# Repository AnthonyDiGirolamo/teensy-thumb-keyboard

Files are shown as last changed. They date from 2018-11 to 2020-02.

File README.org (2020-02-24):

* teensy-thumb-keyboard

  Handheld tactile switch keyboard for Teensy 3.2 compatible boards.

  - [[https://www.tindie.com/products/15575/][Teensy Thumb Keyboard - PCB only]] - Tindie product page and ordering
  - [[https://hackaday.io/project/162281-teensy-thumb-keyboard][hackaday.io page]] - more photos, info and project logs
  - [[https://www.thingiverse.com/thing:3209958][thingiverse 'HyperPixel 4 & Raspberry Pi 3 B+ Handheld' page]]

*** v1.1 Photo
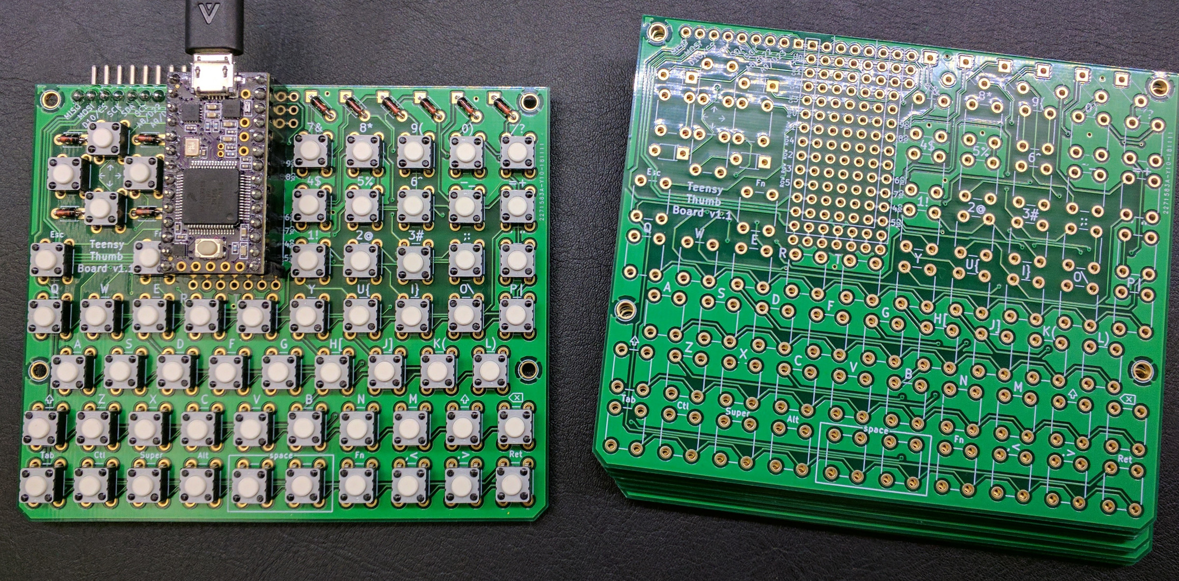
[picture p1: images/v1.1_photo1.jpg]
    

** Features
   - 60 keys arranged in a 6x10 matrix (uses 16 pins on the microcontroller).
   - Silkscreen has a qwerty layout with number keys arranged in a numpad.
   - Lead free ENIG-RoHs surface finish with 2oz copper.
   - SPI, I2C, and 2 additional GPIOs broken out.
   - Each pin along the edge of the Teensy is connected to one extra pin in the
     prototyping area.
   - Beginner friendly through hole soldering.
   - Example Arduino sketch [[https://github.com/AnthonyDiGirolamo/teensy-thumb-keyboard/tree/master/firmware][firmware]] provided. Additional details in the [[https://hackaday.io/project/162281-teensy-thumb-keyboard/log/156138-example-firmware-posted][Example
     Firmware Posted project log]].
   - Layout is completely customizable in the firmware.
   - [[https://github.com/qmk/qmk_firmware][qmk_firmware]] should also work however, I don't have an example running yet.

   *Three possible mounting options*

   1. Teensy on the front, mounted right-side up, with usb port facing north.
   2. Teensy on the back, mounted upside down, with usb port facing north or
      south.
   3. Teensy on the back, mounted upside down, with usb port facing south. Note:
      Breakout pins will only work as expected with USB facing north.

** Parts list for a fully working keyboard

   - 1x [[https://www.pjrc.com/store/teensy32.html][Teensy 3.2]] or [[https://www.pjrc.com/store/teensylc.html][Teensy LC]]. A [[https://www.tindie.com/products/TleraCorp/butterfly-stm32l433-development-board/][Butterfly STM32L433]] will also work (though not
     as a USB keyboard).
   - 10x 1N4148 Zener Diodes
   - 60x Panasonic EVQ-PAC04M Tacticle Switches. These are the quieter and higher
     quality switches. Some are available at [[https://www.digikey.com/products/en?keywords=EVQ-PAC04M][digikey]]. If you wish to use the 3d
     printed faceplate the overall switch height must be 4.3mm. These models will
     also work: EVQ-PAD04M EVQ-PAE04M EVQ-PAG04M. Otherwise any standard 6x6mm
     momentary switch will work.

** Ordering

   - [[https://www.tindie.com/products/15575/][Teensy Thumb Keyboard - PCB only]] Tindie product page
   - Ordering yourself from a PCB manufacturer:
     - https://oshpark.com instructions: upload the [[https://github.com/AnthonyDiGirolamo/teensy-thumb-keyboard/blob/master/hardware/v1.1/teensythumbboard.kicad_pcb][kicad pcb file]] file.
     - https://jlcpcb.com/quote instructions: upload the [[https://github.com/AnthonyDiGirolamo/teensy-thumb-keyboard/blob/master/hardware/v1.1/plots/gerbers.zip][gerber.zip file]] The
       settings I'd recommend are:
       - Layers: 2
       - Thickness: 1
       - Surface finish: LeadFree HASL-RoHs or ENIG-RoHs (don't want lead on a
         board you may be typing on)
       - Copper weight: 2oz (1oz is probably fine though, the heavier weight
         copper stands up better to repeated solder and desoldering I think)
       - Everything else default settings.

** Cases

   - Keyboard Faceplate [[https://a360.co/2QAJ0Qb][Fusion 360 Public Link]]
   - Raspberry Pi 3 B+ & HyperPixel4 Handheld [[https://a360.co/2QzHvla][Fusion 360 Public Link]]

** Firmware

   - The layout for USB keyboarding is defined in the ~usb_key_matrix~ variable
     in [[https://github.com/AnthonyDiGirolamo/teensy-thumb-keyboard/blob/master/firmware/LayoutThumbKeyboard.h#L109][LayoutThumbKeyboard.h]]

   - If you don't need a USB keyboard and are rolling your own hardware project
     then you can focus on the layout defined by the ~ascii_key_matrix~ variable
     in [[https://github.com/AnthonyDiGirolamo/teensy-thumb-keyboard/blob/master/firmware/LayoutThumbKeyboard.h#L74][LayoutThumbKeyboard.h]]

   - There are three layers defined: base, shift, and Fn layers.

   - USB can be disabled by commenting out define ~USE_TEENSY_USB_KEYBOARD~.

   - All the keyboardy goodness is handled by the ~keyboard_update();~ function
     called from inside the standard Arduino ~loop()~.

   - If you don't need the keys to behave like a keyboard you can gut most of
     that example and just use ~key_matrix.update();~ The KeyboardMatrix class
     handles reading the button states.

   - An alternative firmware option for a pure USB keyboard would be to run the
     excellent https://github.com/qmk/qmk_firmware.

*** Compiling on Windows machines

    1. Using a Teensy 3.2 or Teensy LC follow these directions for downloading
       and installing the teensyduino add-on to the Arduino environment:
       https://www.pjrc.com/teensy/td_download.html

    2. Once you have both installed. Launch the Arduino IDE and check what
       version of teensyduino is installed by going to *Help > About
       Arduino*. The about window for me shows *Arduino 1.8.9* in the upper left
       and *Teensyduino 1.46* in the upper right.

    3. Download the code archive from:
       https://github.com/AnthonyDiGirolamo/teensy-thumb-keyboard/archive/master.zip

    4. Extract that folder and move the firmware folder to:
       ~C:\Users\anthony\Documents\Arduino\firmware~ Substitute "anthony" with
       your username.

    5. Rename the ~firmware~ folder to ~teensy32_thumb_keyboard~

       The full path should be:
       ~C:\Users\anthony\Documents\Arduino\teensy32_thumb_keyboard~

       And these files should exist inside there:

       #+BEGIN_SRC text
         KeyboardMatrix.cpp
         KeyboardMatrix.h
         LayoutAppleM0110a.h
         LayoutCommon.h
         LayoutThumbKeyboard.h
         LinkedList.h
         teensy32_thumb_keyboard.ino
       #+END_SRC

    6. Open
       ~C:\Users\anthony\Documents\Arduino\teensy32_thumb_keyboard\teensy32_thumb_keyboard.ino~
       in the arduino IDE.

    7. In the *Tools* menu select *USB Type > Serial + Keyboard + Mouse + Joystick*

    8. Click the verify or upload buttons in the toolbar. If compilation is
       successful you should see a message like:

       #+BEGIN_SRC text
         Sketch uses 27920 bytes (10%) of program storage space. Maximum is 262144 bytes.
         Global variables use 6680 bytes (10%) of dynamic memory, leaving 58856 bytes for local variables. Maximum is 65536 bytes.
       #+END_SRC

*** Uploading the firmware without compiling

    If you don't wish to compile the firmware yourself you can use the
    precompiled hex files provided in the [[https://github.com/AnthonyDiGirolamo/teensy-thumb-keyboard/tree/master/firmware-compiled][firmware-compiled]] folder.

    To get them loaded on a Teensy 3.2 or LC download and install the
    [[https://www.pjrc.com/teensy/loader.html][Teensy Loader Application]] once installed plug in your teensy board and load
    the correct firmware file:

    - [[https://www.pjrc.com/store/teensy32.html][Teensy 3.2]]: ~teensy32_thumb_keyboard.ino-teensy32.hex~
    - [[https://www.pjrc.com/store/teensylc.html][Teensy LC]]: ~teensy32_thumb_keyboard.ino-teensyLC.hex~

** Alternate Versions

   - [[https://github.com/AnthonyDiGirolamo/i2c-thumb-keyboard][i2c-thumb-keyboard]]

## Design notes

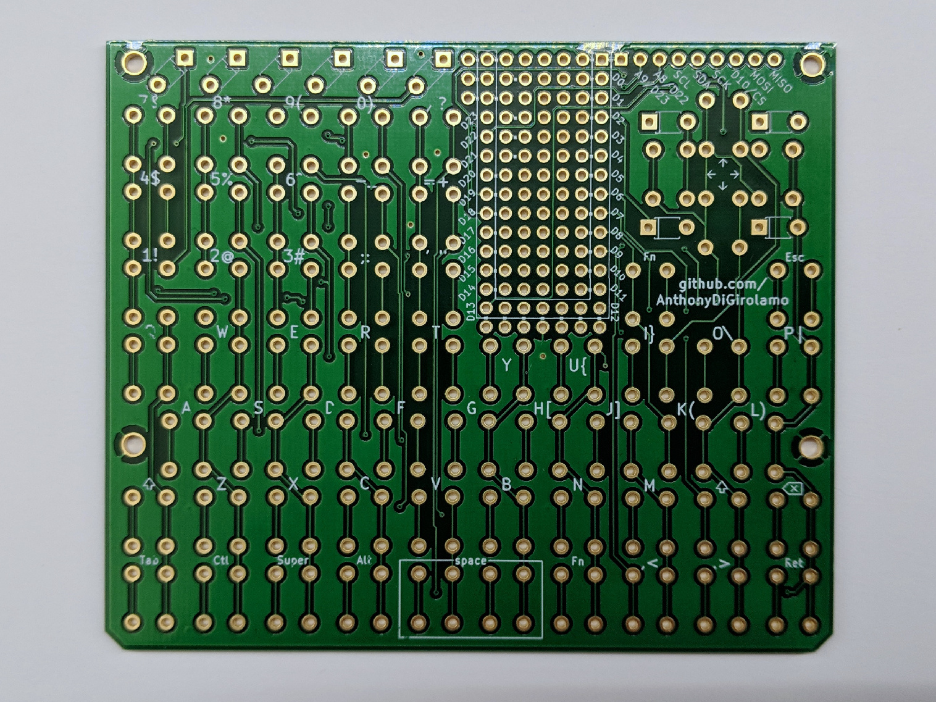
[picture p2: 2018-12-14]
images/ttb_photo_empty_back.jpg

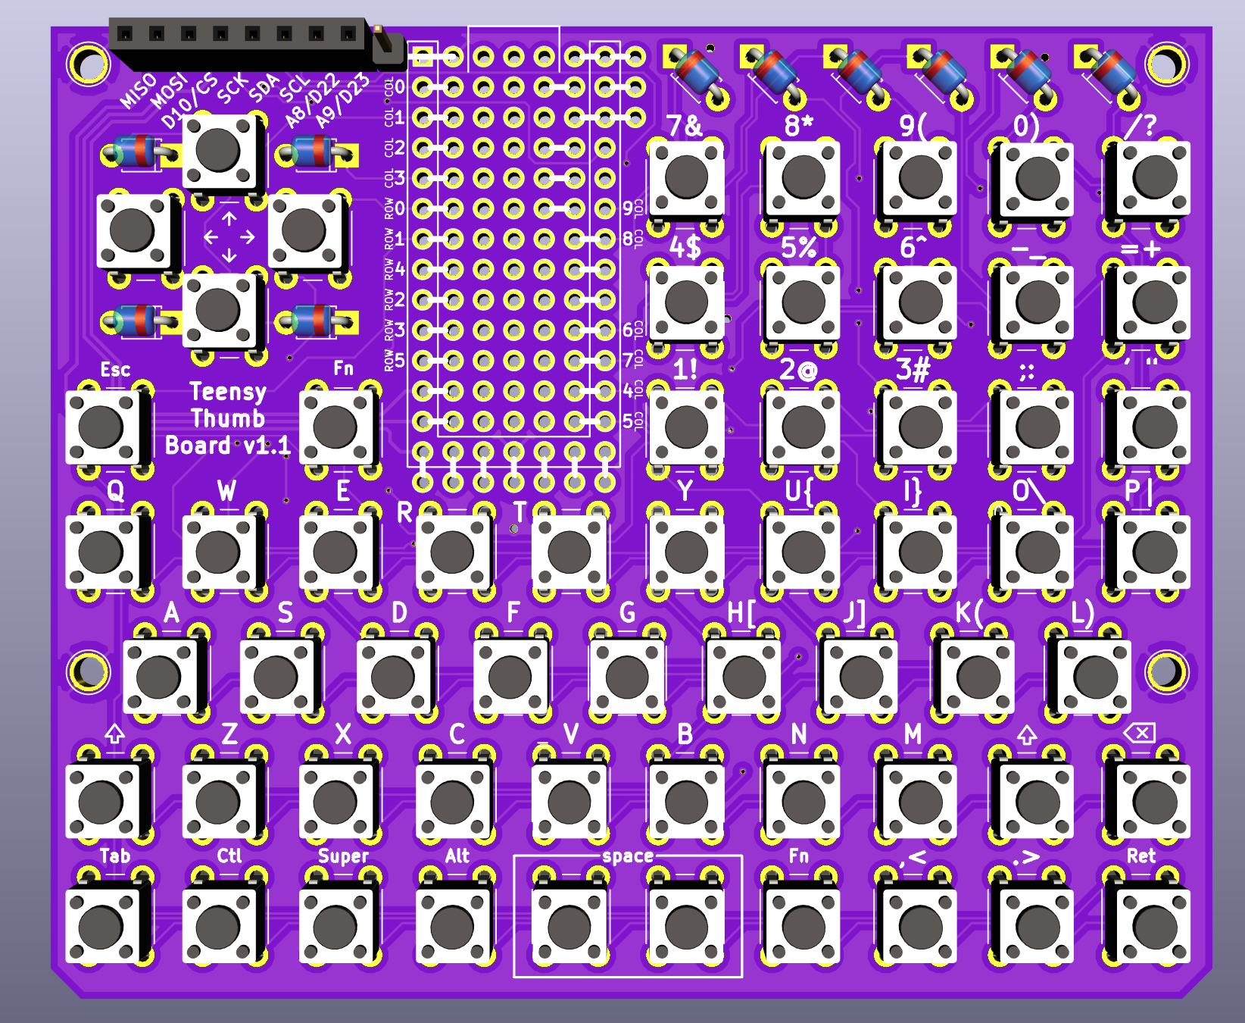
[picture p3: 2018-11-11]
images/v1.1_render.png

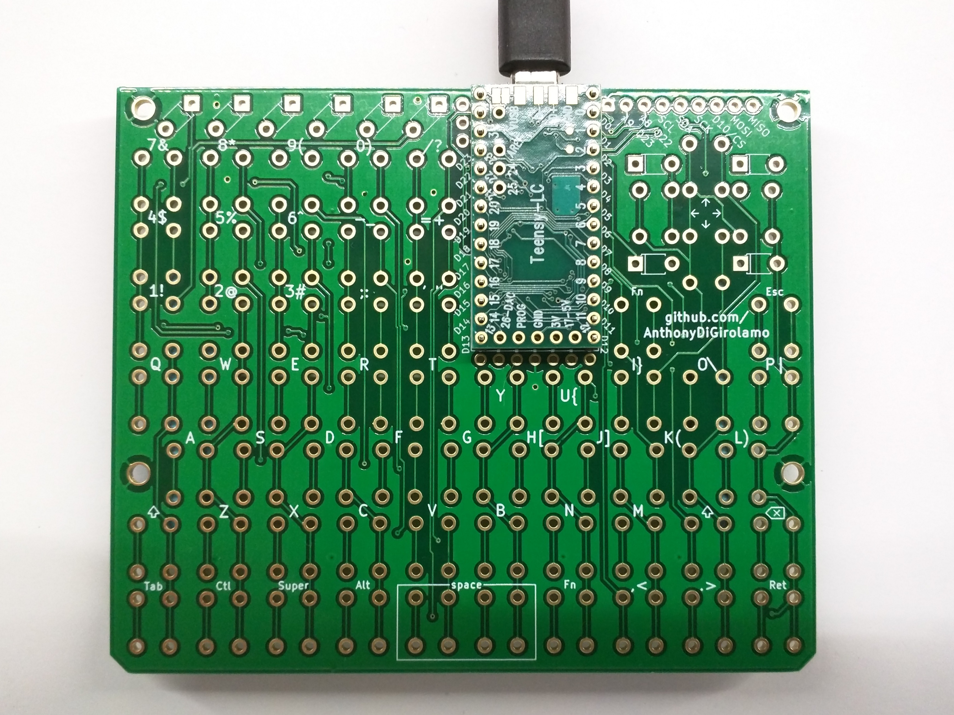
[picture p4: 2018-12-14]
images/ttb_photo_orientation2.jpg

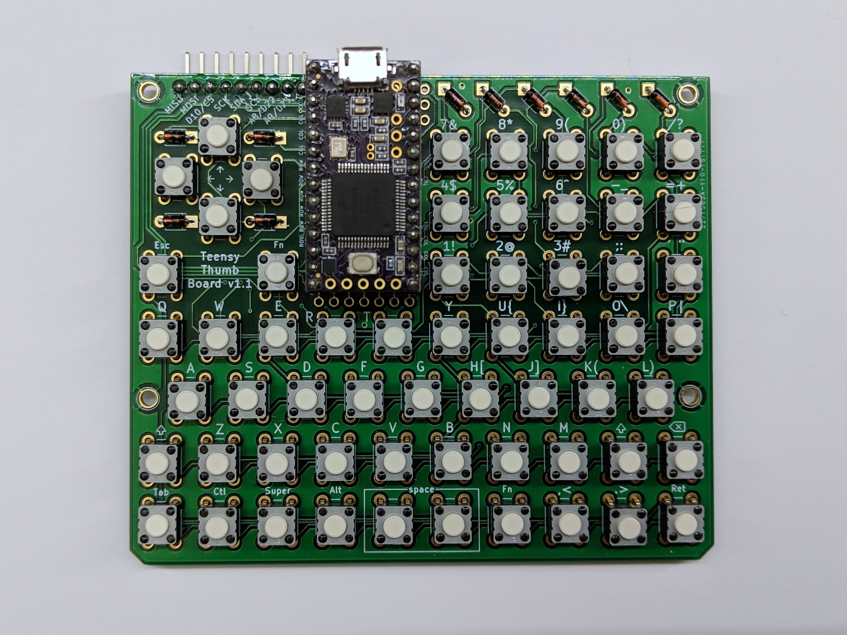
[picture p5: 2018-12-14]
images/ttb_photo_populated.jpg

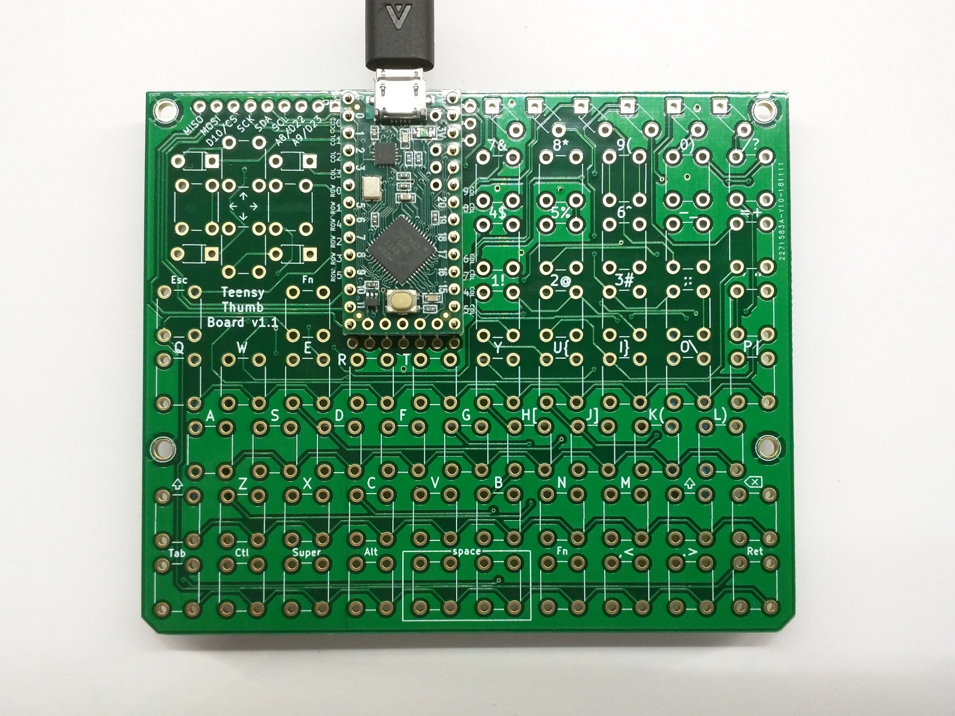
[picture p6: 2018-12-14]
images/ttb_photo_orientation1.jpg

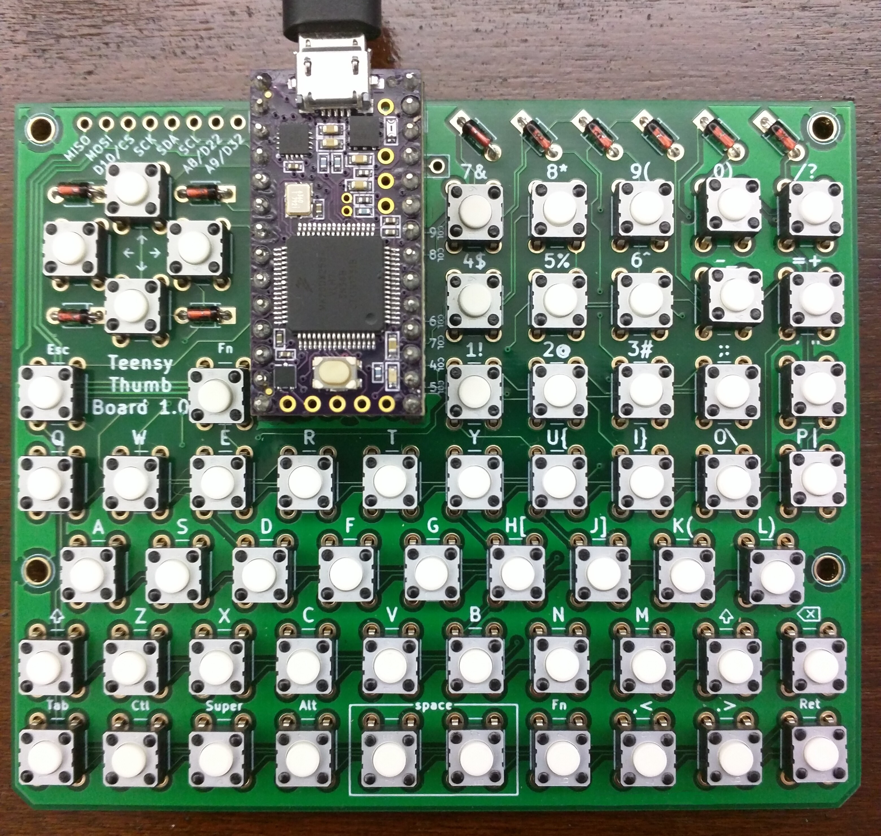
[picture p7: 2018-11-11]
images/v1.0_photo1.jpg

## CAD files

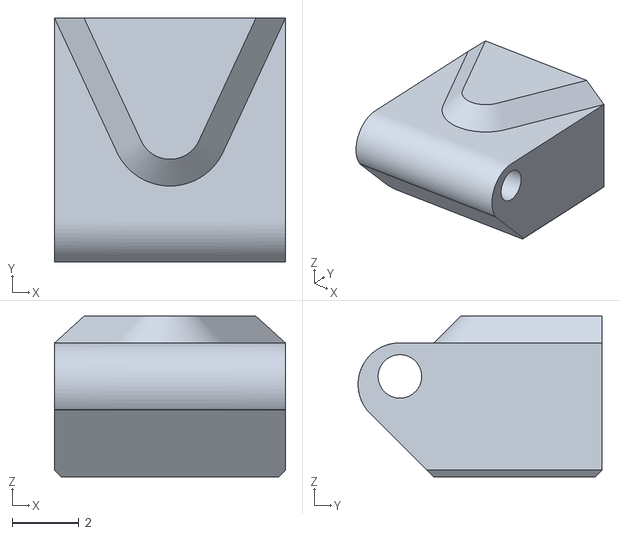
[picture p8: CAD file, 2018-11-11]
case/KeyFaceplate/Key.stl
6.90 x 7.28 x 4.80

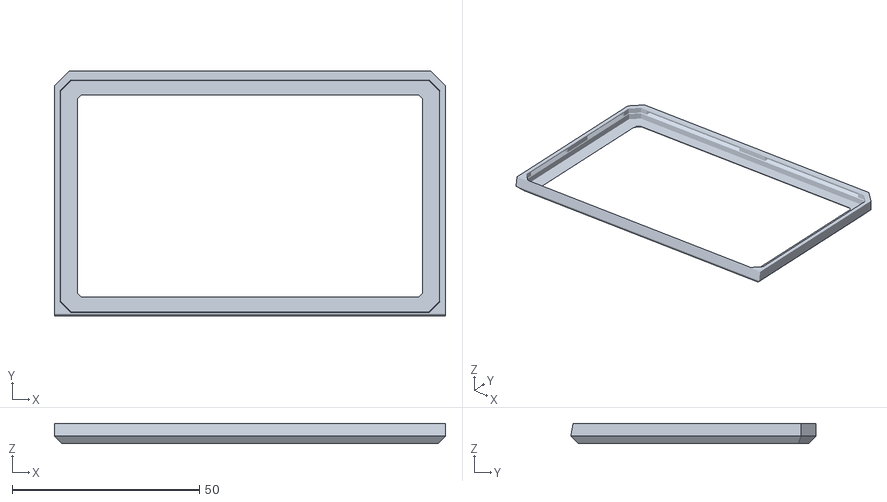
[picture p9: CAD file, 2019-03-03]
case/RaspberryPi3-HyperPixel4-Handheld/LCDBezel-TouchVersion.stl
104.4 x 65.5 x 5.40

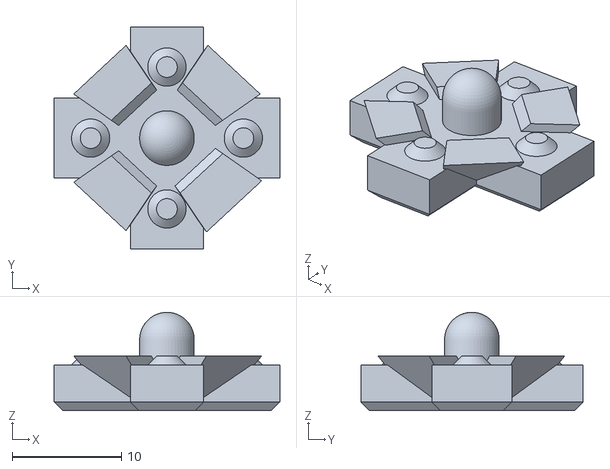
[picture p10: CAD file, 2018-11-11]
case/KeyFaceplate/DPad.stl
20.7 x 20.3 x 9.00

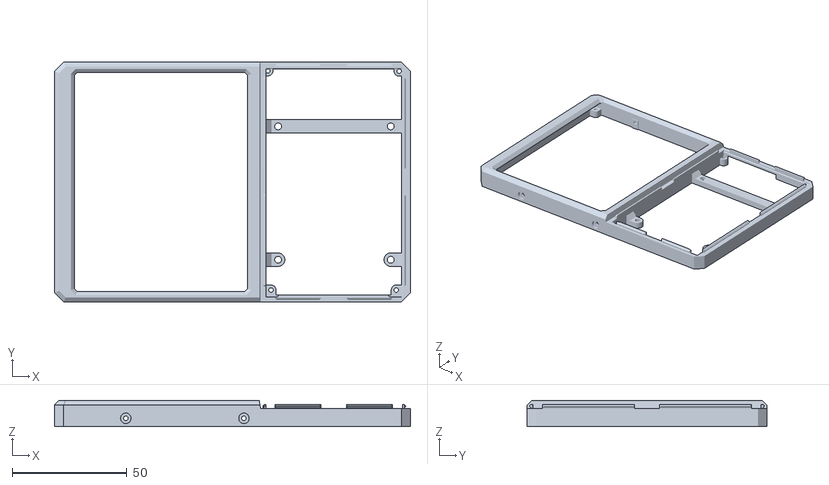
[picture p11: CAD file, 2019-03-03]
case/RaspberryPi3-HyperPixel4-Handheld/Support1_v2.stl
154.9 x 104.4 x 11.4

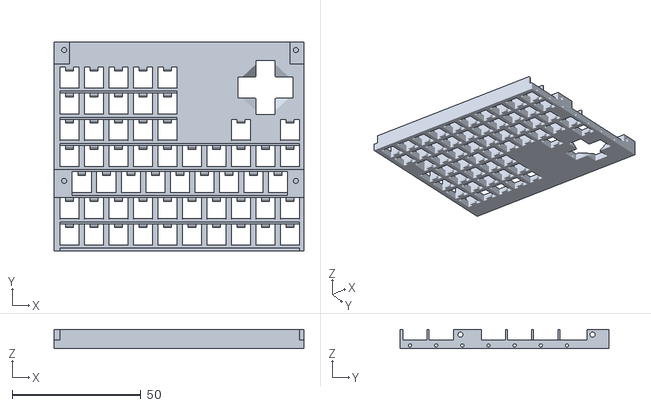
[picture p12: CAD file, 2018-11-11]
case/KeyFaceplate/KeyFaceplate.stl
97.2 x 81.3 x 7.40

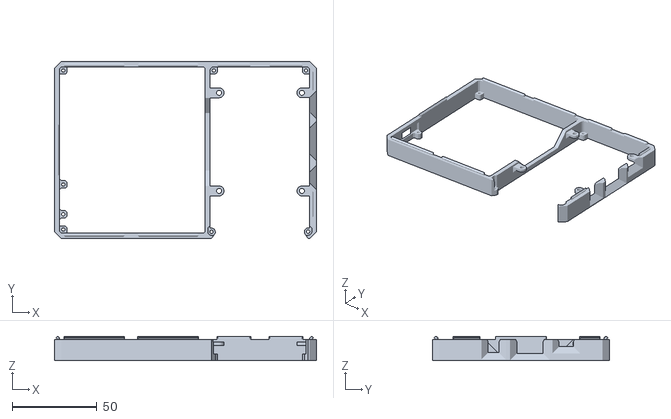
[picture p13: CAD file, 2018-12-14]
case/RaspberryPi3-HyperPixel4-Handheld/Support2.stl
154.9 x 104.4 x 14.4

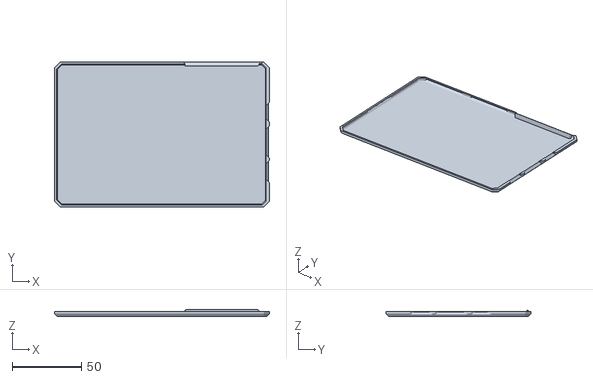
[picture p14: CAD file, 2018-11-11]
case/RaspberryPi3-HyperPixel4-Handheld/Back.stl
154.9 x 104.4 x 4.90

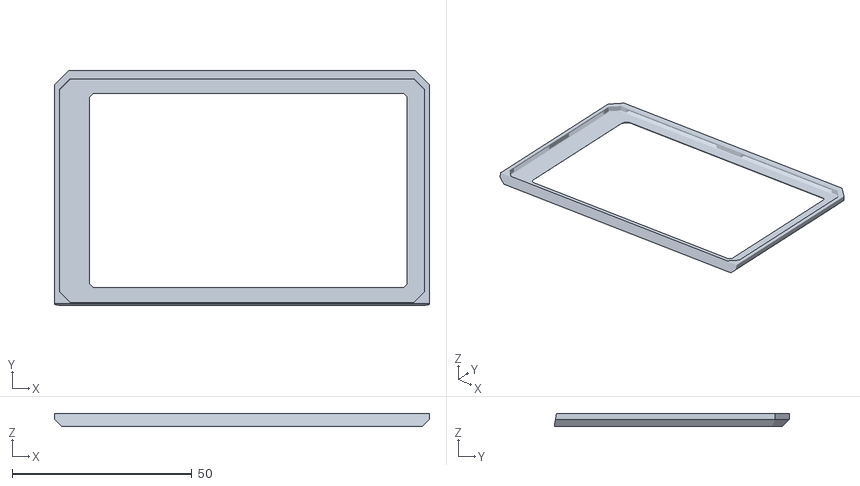
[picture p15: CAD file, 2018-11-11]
case/RaspberryPi3-HyperPixel4-Handheld/LCDBezel-NoTouch.stl
104.4 x 65.5 x 3.60

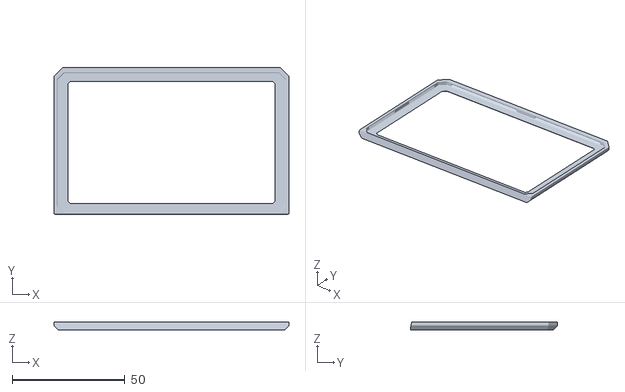
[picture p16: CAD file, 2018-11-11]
case/RaspberryPi3-HyperPixel4-Handheld/LCDBezel-NoTouch-Widened.stl
104.4 x 65.5 x 3.60

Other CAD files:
case/RaspberryPi3-HyperPixel4-Handheld/Support1.stl

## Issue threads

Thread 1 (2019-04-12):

Release example firmware compiled .hex files

0x0f0f0f, 2019-04-12:
on linux the arduino IDE & teensyduino are quite bulky and packages are not available on many distributions, plus, i've already soldered my teensy to the board.

could you please release a compiled example firmware .hex file for the standard USB US keyboard behavior?  `teensy_loader_cli` is easier to build and install rather than the whole arduino ide

AnthonyDiGirolamo, 2019-04-24:
Good idea! I'll get hex files for the teensy 3.2 and LC added soon.

AnthonyDiGirolamo, 2019-07-29:
Finally got around to uploading these. See: https://github.com/AnthonyDiGirolamo/teensy-thumb-keyboard#uploading-the-firmware-without-compiling

Closed 2019-07-29.

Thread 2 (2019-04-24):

Different language layout

teldra, 2019-04-24:
I build this keyboard successfully and it is working when setting Xorg to an english layout. But most of my computers are set to a different keyboard layout (german). So, when I press '/' on the keyboard I get '-'.

How do I change the send keycode, when using 'usb_key_matrix'? Changing 'Tools->Keyboard Layout' to German in Arduino IDE is not working.

AnthonyDiGirolamo, 2019-04-24:
I think it's because I'm using `Keyboard.press()` and `Keyboard.release()`. According to https://www.pjrc.com/teensy/td_keyboard.html the layout option in the arduino IDE only affects `Keyboard.print()` and `Keyboard.write()`. I didn't know that :sweat_smile:

To fix I think you'd have to update or copy [LayoutThumbKeyboard.h](https://github.com/AnthonyDiGirolamo/teensy-thumb-keyboard/blob/master/firmware/LayoutThumbKeyboard.h) to use different key codes in `usb_key_matrix`.

Here's what <kbd>/</kbd> would be with the German layout option:
```c
#define ASCII_2F	KEY_7 + SHIFT_MASK			// 47 /
```

So you'd have to change `KEY_SLASH` in [LayoutThumbKeyboard.h](https://github.com/AnthonyDiGirolamo/teensy-thumb-keyboard/blob/master/firmware/LayoutThumbKeyboard.h#L112) to `KEY_7 + SHIFT_MASK`.

Full list of conversions is in [https://github.com/PaulStoffregen/cores/blob/master/teensy3/keylayouts.h#L562](https://github.com/PaulStoffregen/cores/blob/master/teensy3/keylayouts.h#L562).
You would still need to select German in the Arduino IDE to make sure `SHIFT_MASK` and other defined values are correct.

If you make a new `LayoutGermanThumbKeyboard.h` and send me a pull request I can add it to the repo.

teldra, 2019-04-24:
When I change ```KEY_SLASH``` to  ```KEY_7 + SHIFT_MASK``` I get a ```<```.
And when I set ```KEY_EQUAL``` to ```KEY_0 + SHIFT_MASK``` I get a ```=``` when I press it with or without shift.

teldra, 2019-04-25:
I think I found a solution:
https://github.com/teldra/teensy-thumb-keyboard/blob/master/firmware/KeyboardMatrix.h
https://github.com/teldra/teensy-thumb-keyboard/blob/master/firmware/teensy32_thumb_keyboard.ino
but I wonder, if it is an elegant or correct one. ;) (First time working with Arduino)

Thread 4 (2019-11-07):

Oneshot Shift/Control/Alt/Super not working

Kulllerkeks, 2019-11-07:
After putting all the parts together i recognise that most of the oneShot function isn't working.
oneshot Fn is working fine, Shift seems to have a problem. With the debug messages i can see that the Keys are transmitted in upper case but only lower keys appear in a text box (Tested on Win10 with German keyboard layout in the system settings, Us Layout in Arduino/Teensy settings). I tried using it on a Raspberry pi (Raspbian Buster) with the Layout in Raspbian set to US but encountered the same issue. I also used the Recompiled hex and got the same behavior.

Maybe there was a change in the Teensy libs. It seems that, for normal characters shift needs to be held to get a upper case Character recognized. If i hold shift while pressing another key it is recognized as a upper case character.

Could you try to confirm it? or am i doing something wrong?

And as far as i can see in the firmware, the code for oneshot Control/Alt and Super is missing.

I will try changing the firmware at the weekend but it would be great to know if i am not the only one with this issue.

Otherwise, great work, it helped me tremendously!

Edit: Forgot to mention that i am using a Teensy LC

Closed 2020-10-21.

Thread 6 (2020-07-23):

keyboard not working

graysonmagg, 2020-07-23:
I have ordered the board from JLCpcb, as well as all of the components listed. After soldering everything together, and installing the software, it doesn't work. However, I am testing it just by using it plugged into my MacBook. Is there any troubleshooting tips you'd suggest? I am pretty new to soldering, so I can't tell if it was the soldering, or if it was just me installing the software wrong, so I have attached some pictures as well.

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

RogueColonel, 2020-09-10:
I could be mistaken but I think you've got the Teensy aligned wrongly,

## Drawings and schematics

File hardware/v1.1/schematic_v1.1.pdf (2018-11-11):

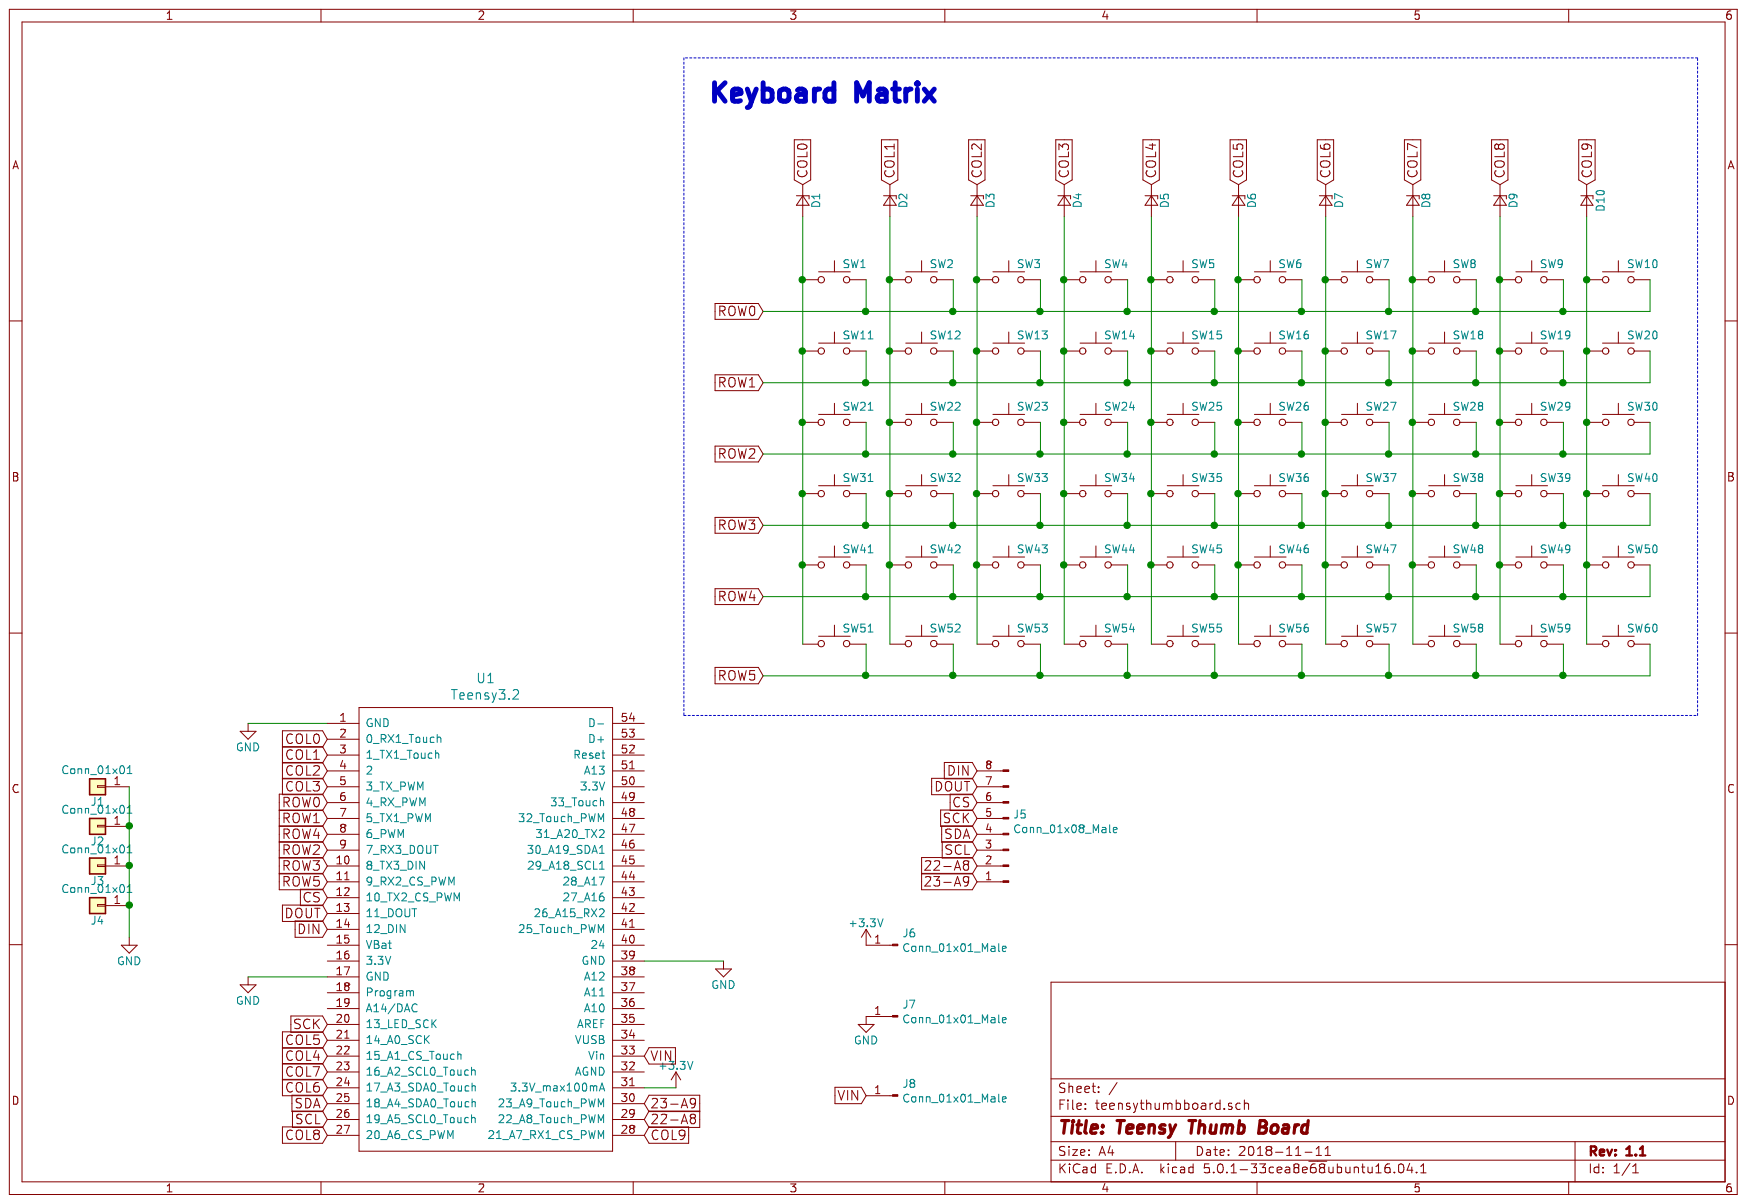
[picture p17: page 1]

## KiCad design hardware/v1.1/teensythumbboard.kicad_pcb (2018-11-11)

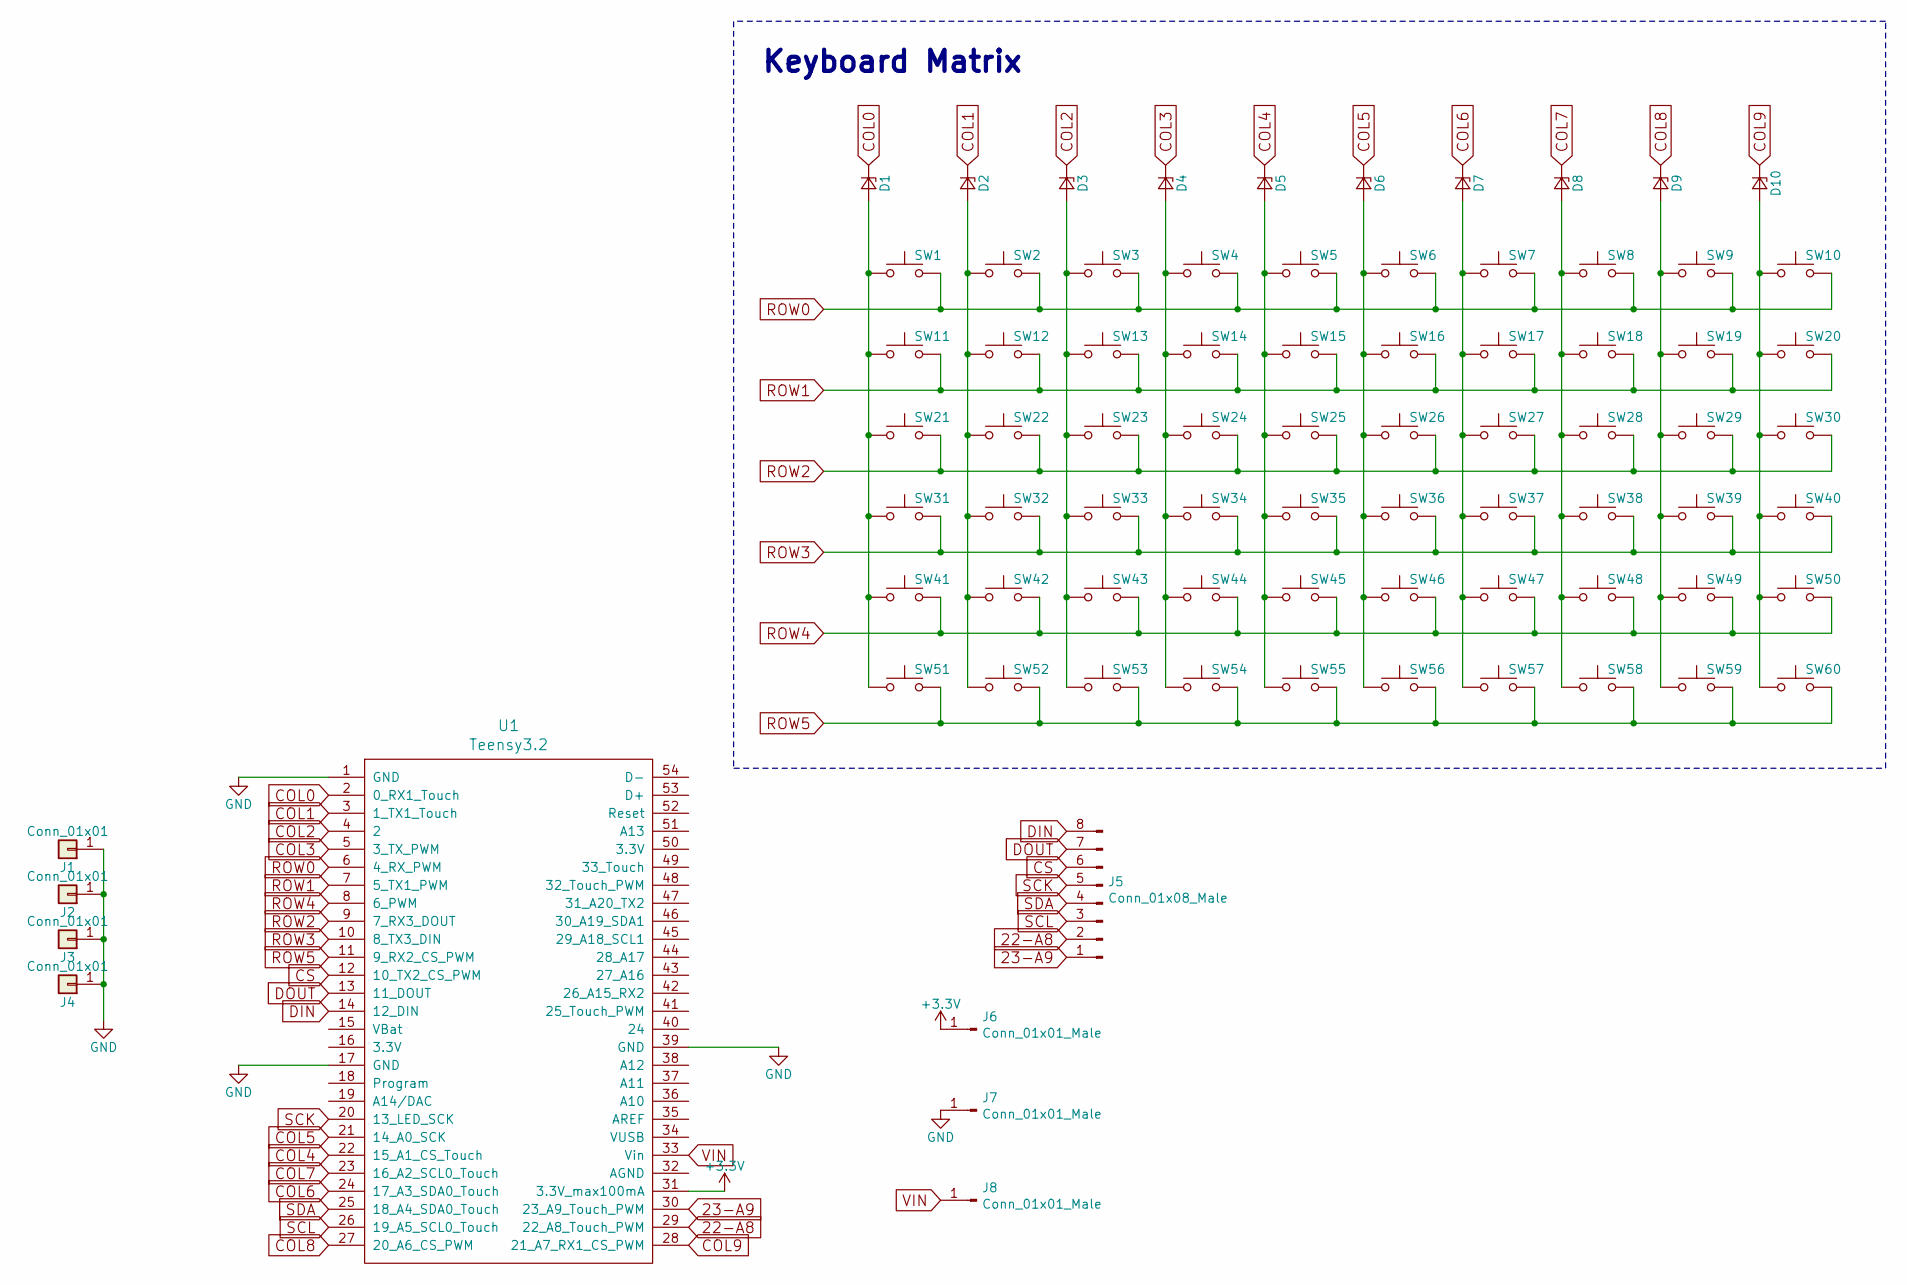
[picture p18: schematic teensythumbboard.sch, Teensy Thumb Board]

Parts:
D1, D2, D3, D4, D5, D6, D7, D8, D9, D10: D_Zener_Small; D_T-1_P5.08mm_Horizontal
J1, J2, J3, J4: Conn_01x01; 2.5MountingHole
J5: Conn_01x08_Male; PinSocket_1x08_P2.54mm_Vertical
J6, J7, J8: Conn_01x01_Male; PinHeader_1x01_P2.54mm_Vertical
SW1, SW2, SW3, SW4, SW5, SW6, SW7, SW8, SW9, SW10, SW11, SW12, SW13, SW14, SW15, SW16, SW17, SW18, SW19, SW20, SW21, SW22, SW23, SW24, SW25, SW26, SW27, SW28, SW29, SW30, SW31, SW32, SW33, SW34, SW35, SW36, SW37, SW38, SW39, SW40, SW41, SW42, SW43, SW44, SW45, SW46, SW47, SW48, SW49, SW50, SW51, SW52, SW53, SW54, SW55, SW56, SW57, SW58, SW59, SW60: SW_Push; SW_PUSH_6mm
U1: Teensy3.2; Teensy32_InnerProto

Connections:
22-A8: J5.2, U1.29 (22_A8_Touch_PWM)
23-A9: J5.1, U1.30 (23_A9_Touch_PWM)
+3V3: J6.1, U1.31 (3.3V_max100mA)
COL0: D1.1 (K), U1.2 (0_RX1_Touch)
COL1: D2.1 (K), U1.3 (1_TX1_Touch)
COL2: D3.1 (K), U1.4 (2)
COL3: D4.1 (K), U1.5 (3_TX_PWM)
COL4: D5.1 (K), U1.22 (15_A1_CS_Touch)
COL5: D6.1 (K), U1.21 (14_A0_SCK)
COL6: D7.1 (K), U1.24 (17_A3_SDA0_Touch)
COL7: D8.1 (K), U1.23 (16_A2_SCL0_Touch)
COL8: D9.1 (K), U1.27 (20_A6_CS_PWM)
COL9: D10.1 (K), U1.28 (21_A7_RX1_CS_PWM)
CS: J5.6, U1.12 (10_TX2_CS_PWM)
DIN: J5.8, U1.14 (12_DIN)
DOUT: J5.7, U1.13 (11_DOUT)
GND: J1.1, J2.1, J3.1, J4.1, J7.1, U1.1 (GND), U1.17 (GND), U1.39 (GND)
unnamed: D1.2 (A), SW1.1, SW11.1, SW21.1, SW31.1, SW41.1, SW51.1
unnamed: D2.2 (A), SW2.1, SW12.1, SW22.1, SW32.1, SW42.1, SW52.1
unnamed: D3.2 (A), SW3.1, SW13.1, SW23.1, SW33.1, SW43.1, SW53.1
unnamed: D4.2 (A), SW4.1, SW14.1, SW24.1, SW34.1, SW44.1, SW54.1
unnamed: D5.2 (A), SW5.1, SW15.1, SW25.1, SW35.1, SW45.1, SW55.1
unnamed: D6.2 (A), SW6.1, SW16.1, SW26.1, SW36.1, SW46.1, SW56.1
unnamed: D7.2 (A), SW7.1, SW17.1, SW27.1, SW37.1, SW47.1, SW57.1
unnamed: D8.2 (A), SW8.1, SW18.1, SW28.1, SW38.1, SW48.1, SW58.1
unnamed: D9.2 (A), SW9.1, SW19.1, SW29.1, SW39.1, SW49.1, SW59.1
unnamed: D10.2 (A), SW10.1, SW20.1, SW30.1, SW40.1, SW50.1, SW60.1
ROW0: SW1.2, SW2.2, SW3.2, SW4.2, SW5.2, SW6.2, SW7.2, SW8.2, SW9.2, SW10.2, U1.6 (4_RX_PWM)
ROW1: SW11.2, SW12.2, SW13.2, SW14.2, SW15.2, SW16.2, SW17.2, SW18.2, SW19.2, SW20.2, U1.7 (5_TX1_PWM)
ROW2: SW21.2, SW22.2, SW23.2, SW24.2, SW25.2, SW26.2, SW27.2, SW28.2, SW29.2, SW30.2, U1.9 (7_RX3_DOUT)
ROW3: SW31.2, SW32.2, SW33.2, SW34.2, SW35.2, SW36.2, SW37.2, SW38.2, SW39.2, SW40.2, U1.10 (8_TX3_DIN)
ROW4: SW41.2, SW42.2, SW43.2, SW44.2, SW45.2, SW46.2, SW47.2, SW48.2, SW49.2, SW50.2, U1.8 (6_PWM)
ROW5: SW51.2, SW52.2, SW53.2, SW54.2, SW55.2, SW56.2, SW57.2, SW58.2, SW59.2, SW60.2, U1.11 (9_RX2_CS_PWM)
SCK: J5.5, U1.20 (13_LED_SCK)
SCL: J5.3, U1.26 (19_A5_SCL0_Touch)
SDA: J5.4, U1.25 (18_A4_SDA0_Touch)
VIN: J8.1, U1.33 (Vin)

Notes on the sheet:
Keyboard Matrix

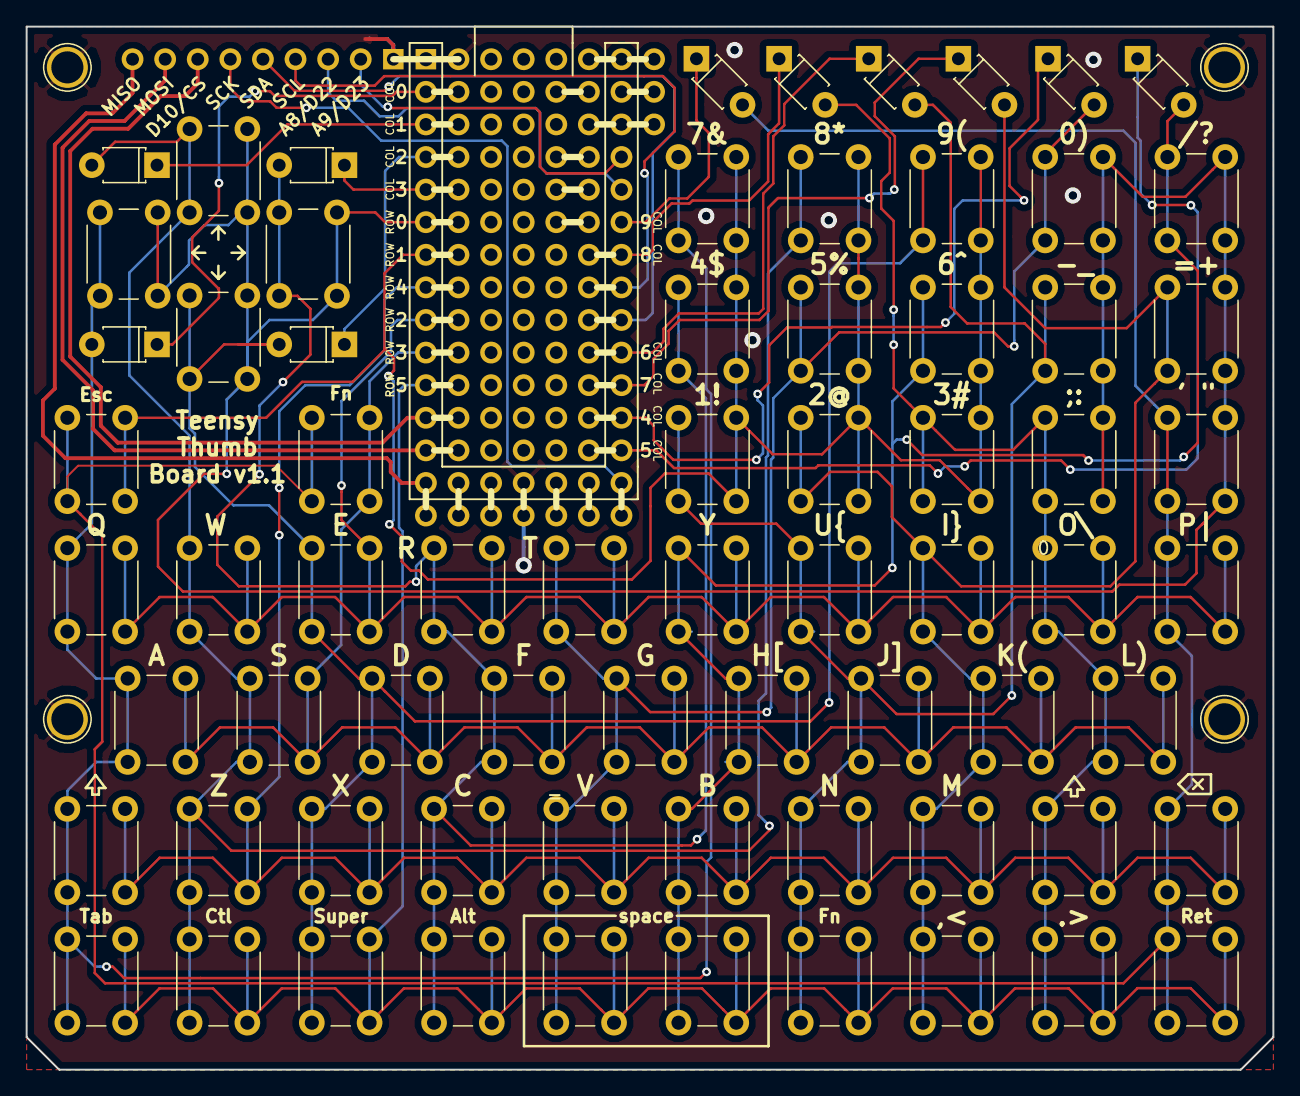
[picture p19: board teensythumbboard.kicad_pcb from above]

Board: 2 copper layers, 97.2 x 81.3 mm, 77 parts (0 on the bottom side), 35 nets.

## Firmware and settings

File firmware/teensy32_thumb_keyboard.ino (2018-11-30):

#include "KeyboardMatrix.h"

// Uncomment to show matrix debug messages over serial
// #define DEBUG


// --- LAYOUT OPTIONS ----------------------------------------------------------

// For TeensyThumbKeyboard:
#include "LayoutThumbKeyboard.h"
KeyboardMatrix key_matrix = KeyboardMatrix(NUM_ROWS, NUM_COLS,
                                           (uint8_t*) row_pins,
                                           (uint8_t*) col_pins,
                                           DIODE_DIRECTION_ROW_PIN_TO_COL_PIN);

// For AppleM0110a:
// #include "LayoutAppleM0110a.h"
// KeyboardMatrix key_matrix = KeyboardMatrix(NUM_ROWS, NUM_COLS,
//                                            (uint8_t*) row_pins,
//                                            (uint8_t*) col_pins,
//                                            DIODE_DIRECTION_COL_PIN_TO_ROW_PIN);

// --- ADDITIONAL FEATURES ----------------------------------------------------------

// Optional USB support using the Teensy Keyboard and Mouse classes
#define USE_TEENSY_USB_KEYBOARD

// Allow a single shift or fn key-press to apply the modifier to the next key press
#define ENABLE_ONESHOT_SHIFT_FN

// Auto-repeat Keypresses in firmware
#define ENABLE_AUTOREPEAT

// Initial delay before repeating a keypress
//   Units are in Microseconds: 1 millisecond = 1000 microseconds
#define HOLD_INTERVAL 300000

// Repeat interval after initial delay
#define REPEAT_INTERVAL 200000

// --- Code --------------------------------------------------------------------

// Represents the current keyboard state between updates
class KeyboardState {
public:
#ifdef ENABLE_ONESHOT_SHIFT_FN
  bool oneshot_shift = false;
  bool oneshot_fn = false;
  bool oneshot_ctrl = false;
  bool oneshot_super = false;
  bool oneshot_alt = false;
#endif

  uint8_t current_layer = 0;
  bool fn_lock = false;
  bool modifier_shift_held = false;
  bool modifier_fn_held = false;
  bool modifier_ctrl_held = false;
  bool modifier_alt_held = false;
  bool modifier_super_held = false;

#ifdef USE_TEENSY_USB_KEYBOARD
  // Mouse keystate variables
  uint8_t mouse_btn1_held = 0;
  uint8_t mouse_btn2_held = 0;
  uint8_t mouse_btn3_held = 0;
  uint8_t mousekey_repeat =  0;
  uint8_t mousekey_accel = 0;
  uint32_t mousekey_last_timer = 0;
#endif

};

KeyboardState keyboard_state = KeyboardState();


// --- Mouse key constants and functions ---------------------------------------
#ifdef USE_TEENSY_USB_KEYBOARD

// User configurable mouse speed values
#define MOUSEKEY_DELAY 100
#define MOUSEKEY_INTERVAL 10
#define MOUSEKEY_MAX_SPEED 7
#define MOUSEKEY_TIME_TO_MAX 255
#define MOUSEKEY_WHEEL_MAX_SPEED 7
#define MOUSEKEY_WHEEL_TIME_TO_MAX 255

#define MOUSEKEY_MOVE_MAX       127
#define MOUSEKEY_WHEEL_MAX      127
#define MOUSEKEY_MOVE_DELTA     5
#define MOUSEKEY_WHEEL_DELTA    1

// Mouse Key implementation from the tmk_keyboard firmware:
// https://github.com/tmk/tmk_keyboard/blob/master/tmk_core/common/mousekey.c

/*
 * Mouse keys acceleration algorithm
 *  http://en.wikipedia.org/wiki/Mouse_keys
 *
 *  speed = delta * max_speed * (repeat / time_to_max)**((1000+curve)/1000)
 */
/* milliseconds between the initial key press and first repeated motion event (0-2550) */
const uint8_t mk_delay = MOUSEKEY_DELAY/10;
/* milliseconds between repeated motion events (0-255) */
const uint8_t mk_interval = MOUSEKEY_INTERVAL;
/* steady speed (in action_delta units) applied each event (0-255) */
const uint8_t mk_max_speed = MOUSEKEY_MAX_SPEED;
/* number of events (count) accelerating to steady speed (0-255) */
const uint8_t mk_time_to_max = MOUSEKEY_TIME_TO_MAX;
/* ramp used to reach maximum pointer speed (NOT SUPPORTED) */
//int8_t mk_curve = 0;
/* wheel params */
const uint8_t mk_wheel_max_speed = MOUSEKEY_WHEEL_MAX_SPEED;
const uint8_t mk_wheel_time_to_max = MOUSEKEY_WHEEL_TIME_TO_MAX;

uint8_t mouse_move_unit(void) {
  uint16_t unit;
  if (keyboard_state.mousekey_accel & (1<<0)) {
    unit = (MOUSEKEY_MOVE_DELTA * mk_max_speed)/4;
  } else if (keyboard_state.mousekey_accel & (1<<1)) {
    unit = (MOUSEKEY_MOVE_DELTA * mk_max_speed)/2;
  } else if (keyboard_state.mousekey_accel & (1<<2)) {
    unit = (MOUSEKEY_MOVE_DELTA * mk_max_speed);
  } else if (keyboard_state.mousekey_repeat == 0) {
    unit = MOUSEKEY_MOVE_DELTA;
  } else if (keyboard_state.mousekey_repeat >= mk_time_to_max) {
    unit = MOUSEKEY_MOVE_DELTA * mk_max_speed;
  } else {
    unit = (MOUSEKEY_MOVE_DELTA * mk_max_speed * keyboard_state.mousekey_repeat) / mk_time_to_max;
  }
  return (unit > MOUSEKEY_MOVE_MAX ? MOUSEKEY_MOVE_MAX : (unit == 0 ? 1 : unit));
}

uint8_t mouse_wheel_unit(void) {
  uint16_t unit;
  if (keyboard_state.mousekey_accel & (1<<0)) {
    unit = (MOUSEKEY_WHEEL_DELTA * mk_wheel_max_speed)/4;
  } else if (keyboard_state.mousekey_accel & (1<<1)) {
    unit = (MOUSEKEY_WHEEL_DELTA * mk_wheel_max_speed)/2;
  } else if (keyboard_state.mousekey_accel & (1<<2)) {
    unit = (MOUSEKEY_WHEEL_DELTA * mk_wheel_max_speed);
  } else if (keyboard_state.mousekey_repeat == 0) {
    unit = MOUSEKEY_WHEEL_DELTA;
  } else if (keyboard_state.mousekey_repeat >= mk_wheel_time_to_max) {
    unit = MOUSEKEY_WHEEL_DELTA * mk_wheel_max_speed;
  } else {
    unit = (MOUSEKEY_WHEEL_DELTA * mk_wheel_max_speed * keyboard_state.mousekey_repeat) / mk_wheel_time_to_max;
  }
  return (unit > MOUSEKEY_WHEEL_MAX ? MOUSEKEY_WHEEL_MAX : (unit == 0 ? 1 : unit));
}
#endif
// end mouse key constants and functions


// Printable character test string
char test_string[64];
uint8_t test_string_index = 0;

// Allow printing (eg with Serial) using the stream operator
template<class T> inline Print& operator <<(Print &obj,     T arg) { obj.print(arg);    return obj; }
template<>        inline Print& operator <<(Print &obj, float arg) { obj.print(arg, 4); return obj; }

int brightness = 200;

static const uint16_t gamma_table_2_5[] = {
        /* gamma = 2.5 */
        0,      0,      0,      1,      2,      4,      6,      8,
        11,     15,     20,     25,     31,     38,     46,     55,
        65,     75,     87,     99,     113,    128,    143,    160,
        178,    197,    218,    239,    262,    286,    311,    338,
        366,    395,    425,    457,    491,    526,    562,    599,
        639,    679,    722,    765,    811,    857,    906,    956,
        1007,   1061,   1116,   1172,   1231,   1291,   1352,   1416,
        1481,   1548,   1617,   1688,   1760,   1834,   1910,   1988,
        2068,   2150,   2233,   2319,   2407,   2496,   2587,   2681,
        2776,   2874,   2973,   3075,   3178,   3284,   3391,   3501,
        3613,   3727,   3843,   3961,   4082,   4204,   4329,   4456,
        4585,   4716,   4850,   4986,   5124,   5264,   5407,   5552,
        5699,   5849,   6001,   6155,   6311,   6470,   6632,   6795,
        6962,   7130,   7301,   7475,   7650,   7829,   8009,   8193,
        8379,   8567,   8758,   8951,   9147,   9345,   9546,   9750,
        9956,   10165,  10376,  10590,  10806,  11025,  11247,  11472,
        11699,  11929,  12161,  12397,  12634,  12875,  13119,  13365,
        13614,  13865,  14120,  14377,  14637,  14899,  15165,  15433,
        15705,  15979,  16256,  16535,  16818,  17104,  17392,  17683,
        17978,  18275,  18575,  18878,  19184,  19493,  19805,  20119,
        20437,  20758,  21082,  21409,  21739,  22072,  22407,  22746,
        23089,  23434,  23782,  24133,  24487,  24845,  25206,  25569,
        25936,  26306,  26679,  27055,  27435,  27818,  28203,  28592,
        28985,  29380,  29779,  30181,  30586,  30994,  31406,  31820,
        32239,  32660,  33085,  33513,  33944,  34379,  34817,  35258,
        35702,  36150,  36602,  37056,  37514,  37976,  38441,  38909,
        39380,  39856,  40334,  40816,  41301,  41790,  42282,  42778,
        43277,  43780,  44286,  44795,  45308,  45825,  46345,  46869,
        47396,  47927,  48461,  48999,  49540,  50085,  50634,  51186,
        51742,  52301,  52864,  53431,  54001,  54575,  55153,  55734,
        56318,  56907,  57499,  58095,  58695,  59298,  59905,  60515,
        61130,  61748,  62370,  62995,  63624,  64258,  64894,  65535,
};

void set_brightness(int b) {
  analogWrite(23, gamma_table_2_5[b]);
}

uint32_t batt_read_millis = millis();

void setup() {
  Serial.begin(115200);
  // delay(2000);
#ifdef DEBUG
  Serial.println("key_matrix.begin();");
#endif

  analogWriteResolution(16);
  set_brightness(brightness);

  key_matrix.begin();

  for (uint8_t i=0; i<63; i++) {
    test_string[i] = ' ';
  }
  test_string[63] = '\0';
#ifdef DEBUG
  Serial.println("Finished setup();");
#endif
}


void print_16_bits_reversed(uint16_t n) {
  char s[17];
  sprintf(s,
          "%d%d%d%d%d%d%d%d%d%d%d%d%d%d%d%d",
          (n & 0x01 ? 1 : 0),
          (n & 0x02 ? 1 : 0),
          (n & 0x04 ? 1 : 0),
          (n & 0x08 ? 1 : 0),
          (n & 0x010 ? 1 : 0),
          (n & 0x020 ? 1 : 0),
          (n & 0x040 ? 1 : 0),
          (n & 0x080 ? 1 : 0),
          (n & 0x0100 ? 1 : 0),
          (n & 0x0200 ? 1 : 0),
          (n & 0x0400 ? 1 : 0),
          (n & 0x0800 ? 1 : 0),
          (n & 0x01000 ? 1 : 0),
          (n & 0x02000 ? 1 : 0),
          (n & 0x04000 ? 1 : 0),
          (n & 0x08000 ? 1 : 0)
          );
  Serial.println(s);
}

bool printable_character(char ascii_key) {
  return ascii_key >= 32 && ascii_key <= 126;
}

void press_backspace() {
  test_string_index = (test_string_index + 62) % 63;
  test_string[test_string_index] = ' ';
}

void press_printable_character(uint8_t ascii_key) {
  // TODO: handle modifiers other than shift/fn. eg Ctrl-C
  test_string[test_string_index] = ascii_key;
  test_string_index = (test_string_index + 1) % 63;
}

void keyboard_update() {
  // reset these on each scan
  bool matrix_changed = false;
  char ascii_key;

  PressedKey *pkey;
  ReleasedKey *rkey;

  // assume modifiers not held
  keyboard_state.modifier_shift_held = false;
  keyboard_state.modifier_fn_held = false;
  keyboard_state.modifier_ctrl_held = false;
  keyboard_state.modifier_alt_held = false;
  keyboard_state.modifier_super_held = false;

  // Scan the key matrix
  matrix_changed = key_matrix.update();

  // check for held modifiers
  for (uint8_t i=0; i<key_matrix.pressed_list.size(); i++) {
    pkey = key_matrix.pressed_list.get(i);

    // button_held requires that the button was initially pressed on the last
    // keyboard scan technically not neccessary here
    if (key_matrix.button_held(pkey->row, pkey->col)) {
      // get layer 0 key
      ascii_key = ascii_key_matrix[0][pkey->row][pkey->col];
      if (ascii_key == ASCII_CTRL)
        keyboard_state.modifier_ctrl_held = true;
      if (ascii_key == ASCII_ALT)
        keyboard_state.modifier_alt_held = true;
      if (ascii_key == ASCII_SUPER)
        keyboard_state.modifier_super_held = true;
      if (ascii_key == ASCII_SHIFT)
        keyboard_state.modifier_shift_held = true;
      if (ascii_key == ASCII_FN)
        keyboard_state.modifier_fn_held = true;
    }
  }  // end check modifiers

  // if matrix changed
  // There should only be one new key press or release per matrix update
  if (matrix_changed) {
    // Print key matrix for debugging
#ifdef DEBUG
    Serial << "\n\n\n";
    // microseconds since last matrix scan
    Serial << "delta_micros: " << key_matrix.delta_micros << '\n';
    for (uint8_t r=0; r<key_matrix.num_rows; r++) {
      Serial << "ROW" << r << ": ";
      print_16_bits_reversed(key_matrix.matrix_state[r]);
    }
#endif

    // Assume layer 0
    keyboard_state.current_layer = 0;

    // change layers for held modifiers (only shift and fn)
    if (keyboard_state.modifier_shift_held)
      keyboard_state.current_layer = 1;
    else if (keyboard_state.modifier_fn_held || keyboard_state.fn_lock)
      keyboard_state.current_layer = 2;

    // process pressed keys
    for (uint8_t i=0; i<key_matrix.pressed_list.size(); i++) {
      pkey = key_matrix.pressed_list.get(i);

#ifdef DEBUG
      Serial << "pressed key: " << pkey->row << ", " << pkey->col << ", " << pkey->hold_time << '\n';
#endif

      // if button just pressed (not being held)
      // if pkey->hold_time > 0 then this is the second or more time the key was seen
      if (pkey->hold_time == 0) {

        ascii_key = ascii_key_matrix[0][pkey->row][pkey->col];

#ifdef ENABLE_ONESHOT_SHIFT_FN
        if (!keyboard_state.fn_lock) {
          // enable or disable oneshot
          if (ascii_key == ASCII_SHIFT) {
            if (keyboard_state.oneshot_shift) {
              // Serial.println("keyboard_state.oneshot_shift = false");
              keyboard_state.oneshot_shift = false;
            }
            // disable onshot if modifier is pressed a second time
            else {
              // Serial.println("keyboard_state.oneshot_shift = true");
              keyboard_state.oneshot_shift = true;
            }
          }
          else if (ascii_key == ASCII_FN) {
            if (keyboard_state.oneshot_fn) {
              // Serial.println("keyboard_state.oneshot_fn = false");
              keyboard_state.oneshot_fn = false;
            }
            // disable onshot if modifier is pressed a second time
            else {
              // Serial.println("keyboard_state.oneshot_fn = true");
              keyboard_state.oneshot_fn = true;
            }
          }

          // change layers for oneshot modes
          if (keyboard_state.oneshot_shift)
            keyboard_state.current_layer = 1;
          else if (keyboard_state.oneshot_fn)
            keyboard_state.current_layer = 2;
        }
#endif

        ascii_key = ascii_key_matrix[keyboard_state.current_layer][pkey->row][pkey->col];

        // Use base layer if key is undefined
        if (ascii_key == 0)
          ascii_key = ascii_key_matrix[0][pkey->row][pkey->col];

#ifdef USE_TEENSY_USB_KEYBOARD
        if (keyboard_state.current_layer == 2) {
          if (printable_character(ascii_key)) {
            Keyboard.print(ascii_key);
          }
          else if (ascii_key == ASCII_MOUSE_BTN1)
            Mouse.click();
          else if (ascii_key == ASCII_MOUSE_BTN2)
            Mouse.click(MOUSE_RIGHT);
          else if (ascii_key == ASCII_MOUSE_BTN3)
            Mouse.click(MOUSE_MIDDLE);
          // TODO: else other keys like mouse buttons?
        }
        else
          Keyboard.press(usb_key_matrix[pkey->row][pkey->col]);
#endif

#ifdef ENABLE_ONESHOT_SHIFT_FN
        // if oneshot is active, and this is not the modifier key, oneshot is used up so set to false
        if (ascii_key != ASCII_SHIFT && keyboard_state.oneshot_shift) {
          // Serial.println("clear keyboard_state.oneshot_shift = false");
          keyboard_state.oneshot_shift = false;
        }
        else if (ascii_key != ASCII_FN && keyboard_state.oneshot_fn) {
          // Serial.println("clear keyboard_state.oneshot_fn = false");
          keyboard_state.oneshot_fn = false;
        }
#endif

        // if backspace
        if (ascii_key == '\b') {
          press_backspace();
        }
        // if printable character
        else if (printable_character(ascii_key)) {
          press_printable_character(ascii_key);
        }
        else if (ascii_key == ASCII_FN_LOCK_TOGGLE)
          keyboard_state.fn_lock = !keyboard_state.fn_lock;

        // TODO: handle more keys
        // else if (ascii_key == ASCII_CTRL) {
        // }
        // else if (ascii_key == ASCII_ALT) {
        // }
        // else if (ascii_key == ASCII_SUPER) {
        // }
        // else if (ascii_key == ASCII_ESC) {
        // }
        // else if (ascii_key == ASCII_UP) {
        // }
        // else if (ascii_key == ASCII_DOWN) {
        // }
        // else if (ascii_key == ASCII_LEFT) {
        // }
        // else if (ascii_key == ASCII_RIGHT) {
        // }
      }  // end if just pressed

    }  // end process pressed keys


    // process released keys
    for (uint8_t i=0; i<key_matrix.released_list.size(); i++) {
      rkey = key_matrix.released_list.get(i);

      // ascii_key = ascii_key_matrix[0][rkey->row][rkey->col];
#ifdef DEBUG
      Serial << "released key: " << rkey->row << ", " << rkey->col << ", " << '\n';
#endif

#ifdef USE_TEENSY_USB_KEYBOARD
      Keyboard.release(usb_key_matrix[rkey->row][rkey->col]);
#endif
    }

    // print test string
#ifdef DEBUG
    Serial.println(test_string);
#endif

  }  // end if matrix updated


#ifdef ENABLE_AUTOREPEAT
  // Auto-repeat the last key held
  if (key_matrix.pressed_list.size() > 0) {
    // get the last key press
    pkey = key_matrix.pressed_list.last_item();

    // check that it's been held long enough
    if (pkey->hold_time > HOLD_INTERVAL) {
      // get keycode value
      ascii_key = ascii_key_matrix[keyboard_state.current_layer][pkey->row][pkey->col];

      if (printable_character(ascii_key)) {
        press_printable_character(ascii_key);
#ifdef DEBUG
        Serial.println(test_string);
#endif
      }
      else if (ascii_key == '\b') {
        press_backspace();
#ifdef DEBUG
        Serial.println(test_string);
#endif
      }
      pkey->hold_time = HOLD_INTERVAL - REPEAT_INTERVAL;
    }
  }
#endif

#ifdef USE_TEENSY_USB_KEYBOARD
  // Mouse key update

  // assume no buttons are held
  keyboard_state.mouse_btn1_held = 0;
  keyboard_state.mouse_btn2_held = 0;
  keyboard_state.mouse_btn3_held = 0;

  bool mouse_left = false;
  bool mouse_up = false;
  bool mouse_down = false;
  bool mouse_right = false;
  bool mouse_wheel_left = false;
  bool mouse_wheel_up = false;
  bool mouse_wheel_down = false;
  bool mouse_wheel_right = false;

  if (millis() - keyboard_state.mousekey_last_timer >
      (keyboard_state.mousekey_repeat ? mk_interval : mk_delay*10)) {

    for (uint8_t i=0; i<key_matrix.pressed_list.size(); i++) {
      pkey = key_matrix.pressed_list.get(i);
      ascii_key = ascii_key_matrix[keyboard_state.current_layer][pkey->row][pkey->col];

      // check for a mousekey press
      if (ascii_key == ASCII_MOUSE_BTN1)
        keyboard_state.mouse_btn1_held = 1;
      else if (ascii_key == ASCII_MOUSE_BTN2)
        keyboard_state.mouse_btn2_held = 1;
      else if (ascii_key == ASCII_MOUSE_BTN3)
        keyboard_state.mouse_btn3_held = 1;

      else if (ascii_key == ASCII_MOUSE_LEFT)
        mouse_left = true;
      else if (ascii_key == ASCII_MOUSE_UP)
        mouse_up = true;
      else if (ascii_key == ASCII_MOUSE_DOWN)
        mouse_down = true;
      else if (ascii_key == ASCII_MOUSE_RIGHT)
        mouse_right = true;

      else if (ascii_key == ASCII_MOUSE_WHEEL_LEFT)
        mouse_wheel_left = true;
      else if (ascii_key == ASCII_MOUSE_WHEEL_UP)
        mouse_wheel_up = true;
      else if (ascii_key == ASCII_MOUSE_WHEEL_DOWN)
        mouse_wheel_down = true;
      else if (ascii_key == ASCII_MOUSE_WHEEL_RIGHT)
        mouse_wheel_right = true;
    }

    // is there a mousekey (move command)
    if (mouse_left || mouse_up || mouse_down || mouse_right ||
        mouse_wheel_left || mouse_wheel_up || mouse_wheel_down || mouse_wheel_right) {
      if (keyboard_state.mousekey_repeat != UINT8_MAX)
        keyboard_state.mousekey_repeat++;

      Mouse.set_buttons(keyboard_state.mouse_btn1_held, keyboard_state.mouse_btn2_held, keyboard_state.mouse_btn3_held);

      int8_t x = 0, y = 0;

      if (mouse_left)
        x = -mouse_move_unit();
      else if (mouse_right)
        x = mouse_move_unit();

      if (mouse_up)
        y = -mouse_move_unit();
      else if (mouse_down)
        y = mouse_move_unit();

      // slow down diagonal moves
      if (x != 0 && y != 0) {
        x *= 0.7;
        y *= 0.7;
      }

      int8_t wheelx = 0, wheely = 0;

      if (mouse_wheel_up)
        wheelx = -mouse_wheel_unit();
      else if (mouse_wheel_down)
        wheelx = mouse_wheel_unit();

      if (mouse_wheel_left)
        wheely = -mouse_wheel_unit();
      else if (mouse_wheel_right)
        wheely = mouse_wheel_unit();

#ifdef DEBUG
      Serial << "[Mouse] repeat: " << keyboard_state.mousekey_repeat << " accel: " << keyboard_state.mousekey_accel << " move: (" << x << ", " << y << ")\n";
#endif
      Mouse.move(x, y, wheelx, wheely);
    }
    else {
      // release any held buttons
      Mouse.set_buttons(0, 0, 0);
      // not moving reset repeat and accel
      keyboard_state.mousekey_repeat = 0;
      keyboard_state.mousekey_accel = 0;
    }

    keyboard_state.mousekey_last_timer = millis();
  }


#endif

}


void loop() {
  // Check Battery pin every 3seconds
  if (millis() > (batt_read_millis + 3000)) {
    float batt = 3.3 * ((float) analogRead(22) / 1024.0);
    Serial << "Batt:" << batt << "\n";
    batt_read_millis = millis();
  }

  // Run the keyboard update routine
  keyboard_update();

  // Check for brightness up / down keys
  PressedKey *pkey;
  uint8_t ak;

  // Is the Fn modifier key held?
  if (keyboard_state.modifier_fn_held == true) {

    // for each pressed key
    for (uint8_t i=0; i<key_matrix.pressed_list.size(); i++) {
      // get the key
      pkey = key_matrix.pressed_list.get(i);

      // If key just pressed then hold_time == 0
      // (if pkey->hold_time > 0 then this is the second or higher time the key was seen)
      if (pkey->hold_time == 0) {
        ak = ascii_key_matrix[keyboard_state.current_layer][pkey->row][pkey->col];
        // Use base layer if key is undefined
        if (ak == 0)
          ak = ascii_key_matrix[0][pkey->row][pkey->col];

        // Fn + < (comma key)
        if (ak == '.') {
          brightness += 5;
          if (brightness > 255)
            brightness = 255;
          set_brightness(brightness);
        }
        // Fn + > (period key)
        else if (ak == ',') {
          brightness -= 5;
          if (brightness < 5)
            brightness = 5;
          set_brightness(brightness);
        }
      }
    }
  }
}

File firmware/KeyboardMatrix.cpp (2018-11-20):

#include "KeyboardMatrix.h"

PressedKey::PressedKey(uint8_t key_row, uint8_t key_column, uint32_t initial_hold_time) {
  row = key_row;
  col = key_column;
  hold_time = initial_hold_time;
}

// uint8_t PressedKey::row() {return _row;}
// uint8_t PressedKey::col() {return _col;}
// uint32_t PressedKey::hold_time() {return _hold_time;}

ReleasedKey::ReleasedKey(uint8_t key_row, uint8_t key_column) {
  row = key_row;
  col = key_column;
}

// uint8_t ReleasedKey::row() {return _row;}
// uint8_t ReleasedKey::col() {return _col;}

KeyboardMatrix::KeyboardMatrix(uint8_t numrows, uint8_t numcols,
                               uint8_t *rowpins, uint8_t *colpins,
                               uint8_t diodedir) {
  diode_direction = diodedir;
  num_rows = numrows;
  num_cols = numcols;
  row_pins = (uint8_t*) rowpins;
  col_pins = (uint8_t*) colpins;

  delta_micros = 0;
  last_update_micros = 0;
  this_update_micros = 0;

  this_row_read = new uint16_t[num_rows];
  matrix_state = new uint16_t[num_rows];
  matrix_state_prev = new uint16_t[num_rows];
  key_states = new debounced_switch[num_rows*num_cols];
}

KeyboardMatrix::~KeyboardMatrix(void) {
  delete [] this_row_read;
  delete [] matrix_state_prev;
  delete [] matrix_state;
  delete [] key_states;
}

void KeyboardMatrix::begin(void) {
  if (diode_direction == DIODE_DIRECTION_COL_PIN_TO_ROW_PIN) {
    // Set col pins to input and turn on pullups
    for (uint8_t i=0; i<num_cols; i++) {
      pinMode(col_pins[i], INPUT_PULLUP);
    }

    // Set row pins to input - this is the 'deactivated' state
    for (uint8_t i=0; i<num_rows; i++) {
      pinMode(row_pins[i], INPUT);
    }
  }
  else if (diode_direction == DIODE_DIRECTION_ROW_PIN_TO_COL_PIN) {
    // Set row pins to input and turn on pullups
    for (uint8_t i=0; i<num_rows; i++) {
      pinMode(row_pins[i], INPUT_PULLUP);
    }

    // Set col pins to input - this is the 'deactivated' state
    for (uint8_t i=0; i<num_cols; i++) {
      pinMode(col_pins[i], INPUT);
    }
  }

  // init default values
  for (uint8_t row=0; row<num_rows; row++) {
    this_row_read[row] = 0xFFFF;
    matrix_state[row] = 0xFFFF;
    matrix_state_prev[row] = 0xFFFF;

    for (uint8_t col=0; col<num_cols; col++) {
      // hold_time[row][col] = 0;

      // init key_states to not pressed
      key_states[row*num_cols+col].counter = -STEADY_COUNT;
      key_states[row*num_cols+col].state = 0;
    }
  }
}

bool KeyboardMatrix::debounce_update(uint8_t r, uint8_t c) {
  uint16_t index = r*num_cols+c;
  // if button state is active
  if (0 == (this_row_read[r] & (1<<c))) {
    // Serial.print("positive read row: ");
    // Serial.print(r);
    // Serial.print("col: ");
    // Serial.print(c);
    // Serial.print("counter increment ");
    // Serial.print(key_states[index].counter);
    // Serial.print(" -> ");
    if (key_states[index].counter < +STEADY_COUNT)
      ++key_states[index].counter;
    // Serial.println(key_states[index].counter);
  }
  else {
    if (key_states[index].counter > -STEADY_COUNT)
      --key_states[index].counter;
  }
  switch (key_states[index].state) {
  case 0: // steady-state lo
    if (key_states[index].counter >= -TRANSIENT_COUNT_ABS) {
      // => transient lo-hi
      // Serial.print("Pressed Transient ");
      // Serial.print(ascii_key_matrix[0][r][c]);
      // Serial.print(" counter: ");
      // Serial.println(key_states[index].counter);
      key_states[index].counter = 0;
      key_states[index].state = 1;
      return true;
    } else {
      return false;
    }
  case 1: // transient lo-hi
    switch (key_states[index].counter) {
    case +STEADY_COUNT:
      // => steady-state hi
      // Serial.print("Pressed Steady ");
      // Serial.print(ascii_key_matrix[0][r][c]);
      // Serial.print(" counter: ");
      // Serial.println(key_states[index].counter);
      key_states[index].state = 2;
      return false;
    case -STEADY_COUNT:
      // => steady-state lo
      key_states[index].state = 0;
      return true;
    default:
      return false;
    }
  case 2: // steady-state hi
    if (key_states[index].counter <= +TRANSIENT_COUNT_ABS) {
      // => transient hi-lo
      // Serial.print("Released Transient ");
      // Serial.print(ascii_key_matrix[0][r][c]);
      // Serial.print(" counter: ");
      // Serial.println(key_states[index].counter);
      key_states[index].counter = 0;
      key_states[index].state = 3;
      return true;
    } else {
      return false;
    }
  case 3: // transient hi-lo
    switch (key_states[index].counter) {
    case +STEADY_COUNT:
      // => steady-state hi
      key_states[index].state = 2;
      return true;
    case -STEADY_COUNT:
      // => steady-state lo
      // Serial.print("Released Steady ");
      // Serial.print(ascii_key_matrix[0][r][c]);
      // Serial.print(" counter: ");
      // Serial.println(key_states[index].counter);
      key_states[index].state = 0;
      return false;
    default:
      return false;
    }
  default:
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

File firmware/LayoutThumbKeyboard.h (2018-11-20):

#ifndef LAYOUTTHUMBKEYBOARD_H
#define LAYOUTTHUMBKEYBOARD_H

#include <Arduino.h>
#include "LayoutCommon.h"

#define NUM_ROWS 6
#define NUM_COLS 10

// USB Facing Up
// Row Pins
#define ROW0 4
#define ROW1 5
#define ROW2 7
#define ROW3 8
#define ROW4 6
#define ROW5 9
// Column Pins
#define COL0 0
#define COL1 1
#define COL2 2
#define COL3 3
#define COL4 15
#define COL5 14
#define COL6 17
#define COL7 16
#define COL8 20
#define COL9 21

// // USB Facing Down
// // Row Pins
// #define ROW0 18
// #define ROW1 19
// #define ROW2 21
// #define ROW3 22
// #define ROW4 20
// #define ROW5 23
// // Column Pins
// #define COL0 14
// #define COL1 15
// #define COL2 16
// #define COL3 17
// #define COL4 1
// #define COL5 0
// #define COL6 3
// #define COL7 2
// #define COL8 6
// #define COL9 7

const uint8_t row_pins[] =
  {
   ROW0,
   ROW1,
   ROW2,
   ROW3,
   ROW4,
   ROW5,
  };

const uint8_t col_pins[] =
  {
   COL0,
   COL1,
   COL2,
   COL3,
   COL4,
   COL5,
   COL6,
   COL7,
   COL8,
   COL9,
  };

const char ascii_key_matrix[3][NUM_ROWS][NUM_COLS] =
  {
   // Base Layer
   {
    {ASCII_LEFT,  ASCII_UP,   ASCII_DOWN,  ASCII_RIGHT, '0', '/', '-',      '=', ';',         39}, // 39 = single quote
    {'7',         '8',        '9',         '4',         '5', '6', '1',      '2', '3',         ASCII_ESC},
    {'q',         'w',        'e',         'r',         't', 'y', 'u',      'i', 'o',         'p'},
    {'a',         's',        'd',         'f',         'g', 'h', 'j',      'k', 'l',         ASCII_FN},
    {ASCII_SHIFT, 'z',        'x',         'c',         'v', 'b', 'n',      'm', ASCII_SHIFT, '\b'},
    {'\t',        ASCII_CTRL, ASCII_SUPER, ASCII_ALT,   ' ', ' ', ASCII_FN, ',', '.',         '\n'},
   },
   // Shift Layer
   {
    {0,   0,   0,   0,   ')', '?', '_', '+', ':',  '"'},
    {'&', '*', '(', '$', '%', '^', '!', '@', '#',  0},
    {'Q', 'W', 'E', 'R', 'T', 'Y', 'U', 'I', 'O',  'P'},
    {'A', 'S', 'D', 'F', 'G', 'H', 'J', 'K', 'L',  0},
    {0,   'Z', 'X', 'C', 'V', 'B', 'N', 'M', 0,    0},
    {0,   0,   0,   0,   0,   0,   0,   '<', '>',  0},
   },
   // Fn Layer
   {
    {ASCII_MOUSE_LEFT,     ASCII_MOUSE_UP, ASCII_MOUSE_DOWN, ASCII_MOUSE_RIGHT,      0, 0,                    ASCII_MOUSE_BTN2, ASCII_MOUSE_BTN3, 0,    96},
    {ASCII_MOUSE_WHEEL_UP, 0,              0,                ASCII_MOUSE_WHEEL_DOWN, 0, ASCII_MOUSE_BTN1,     0,                0,                0,    126},
    {0,                    0,              0,                0,                      0, 0,                    '{',              '}',              '\\', '|'},
    {0,                    0,              0,                0,                      0, '[',                  ']',              '(',              ')',  0},
    {0,                    0,              0,                0,                      0, 0,                    0,                0,                0,    0},
    {0,                    0,              0,                0,                      0, ASCII_FN_LOCK_TOGGLE, 0,                0,                0,    0},
   },
  };


// for all keycodes see:
// ~/apps/arduino-1.8.5/hardware/teensy/avr/cores/teensy3/keylayouts.h
// https://www.pjrc.com/teensy/td_keyboard.html
const uint16_t usb_key_matrix[NUM_ROWS][NUM_COLS] =
  // Base Layer
  {
   {KEY_LEFT,          KEY_UP,           KEY_DOWN,        KEY_RIGHT,       KEY_0,     KEY_SLASH, KEY_MINUS, KEY_EQUAL, KEY_SEMICOLON,     KEY_QUOTE},
   {KEY_7,             KEY_8,            KEY_9,           KEY_4,           KEY_5,     KEY_6,     KEY_1,     KEY_2,     KEY_3,             KEY_ESC},
   {KEY_Q,             KEY_W,            KEY_E,           KEY_R,           KEY_T,     KEY_Y,     KEY_U,     KEY_I,     KEY_O,             KEY_P},
   {KEY_A,             KEY_S,            KEY_D,           KEY_F,           KEY_G,     KEY_H,     KEY_J,     KEY_K,     KEY_L,             ASCII_FN},
   {MODIFIERKEY_SHIFT, KEY_Z,            KEY_X,           KEY_C,           KEY_V,     KEY_B,     KEY_N,     KEY_M,     MODIFIERKEY_SHIFT, KEY_BACKSPACE},
   {KEY_TAB,           MODIFIERKEY_CTRL, MODIFIERKEY_GUI, MODIFIERKEY_ALT, KEY_SPACE, KEY_SPACE, ASCII_FN,  KEY_COMMA, KEY_PERIOD,        KEY_ENTER},
  };

#endif

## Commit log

2018-11-11 Add v1.0 kicad project
    [teensythumbboard-B.Cu.gbr, teensythumbboard-B.Mask.gbr, teensythumbboard-B.SilkS.gbr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]
2018-11-11 Add v1.1 kicad project
    [teensythumbboard-2018-07-13-08-14-04.sch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]
2018-11-11 Update README, add images and stls
    [Back.stl, DPad.stl, Key.stl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]
2018-12-14 update Support2 to be rotated correctly, add more photos
    [Support2.stl]
2019-03-03 Add LCDBezel-TouchVersion.stl and Support1_v2.stl (adds additional screen pcb clearance).
    [LCDBezel-TouchVersion.stl, Support1_v2.stl]
2020-02-24 Add link to the i2c-thumb-keyboard repo
